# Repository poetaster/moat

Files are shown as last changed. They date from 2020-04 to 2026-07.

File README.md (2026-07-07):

# moat / Keep

A fritzing project to build a semi modular pocket synth. An analog companion to Bastl instruments Kastle. 
Find Kastle source here: https://github.com/bastl-instruments/kastle 

Keep (and moat), unlike Kastle, is analog. It uses a Hex Schmitt-trigger (40106be) for pulses (lfo/osc), a binary ripple counter (4040) for sequencing and an XR 2206 for FM and AM audio. And (very) primitive filters. It sequences using the binary ripple counter, mashed :) Now this actually refers to keep, and Moat has been reborn. See below.

The XR features 2 FM inputs and one AM input. The waveshape of the XR can be tuned from brash triangle to simple sine. The XOR is providing on LFO pulse and one square wave OSC. And everything modulates:)

The moat and keep projects have actuall diverged (see below for Moat and Moat shark) but I haven't had a chance to move to new repo structures.

Some audio samples can be found here: https://poetaster.org/keep . You can also order a kit to make it from me :) I also sell on https://tonetoys.etsy.com and Tindie.

## Sales, yes, I'll sell you some :)

. I'm also on bigcartel at https://tonetoys.bigcartel.com/ ....

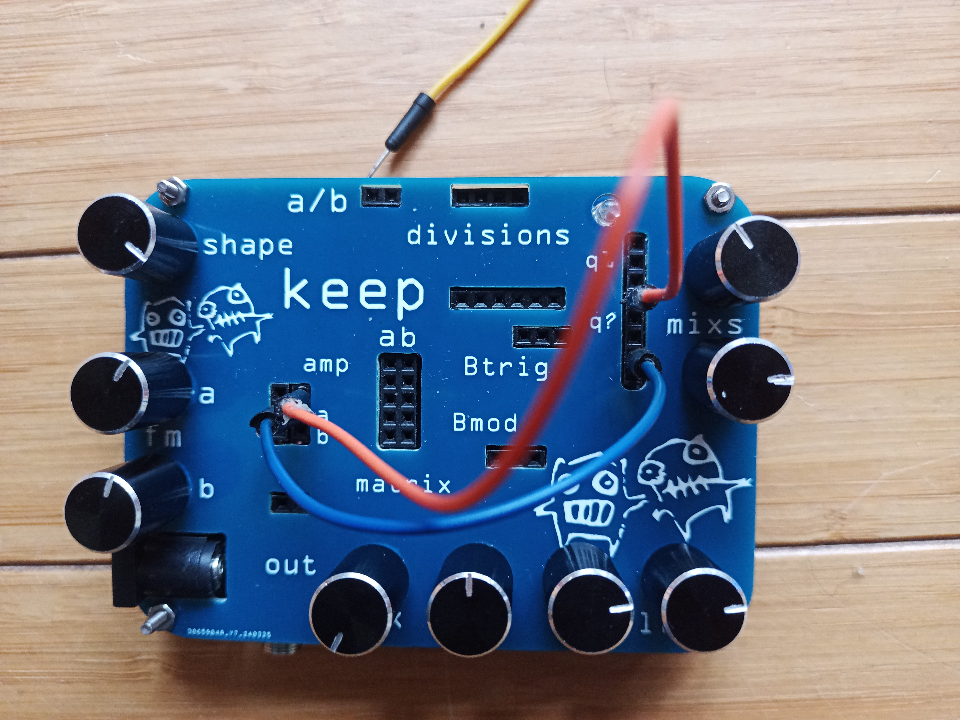
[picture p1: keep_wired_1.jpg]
v4 keep


It's a self-sequencing, semi-modular, pocket synth. Props to minimo, bastl, minty synth etc!

## keep, Version 4 is now in production. 

''Don't use the old moat fritzing projects''.

Version 4 adds waveshaping on the amplitude modulation input, changes the order of the sequencer mix and adds outputs on the rest of the 4040 Q outputs. Otherwise, it adds more space, especially to ease installing vactrol

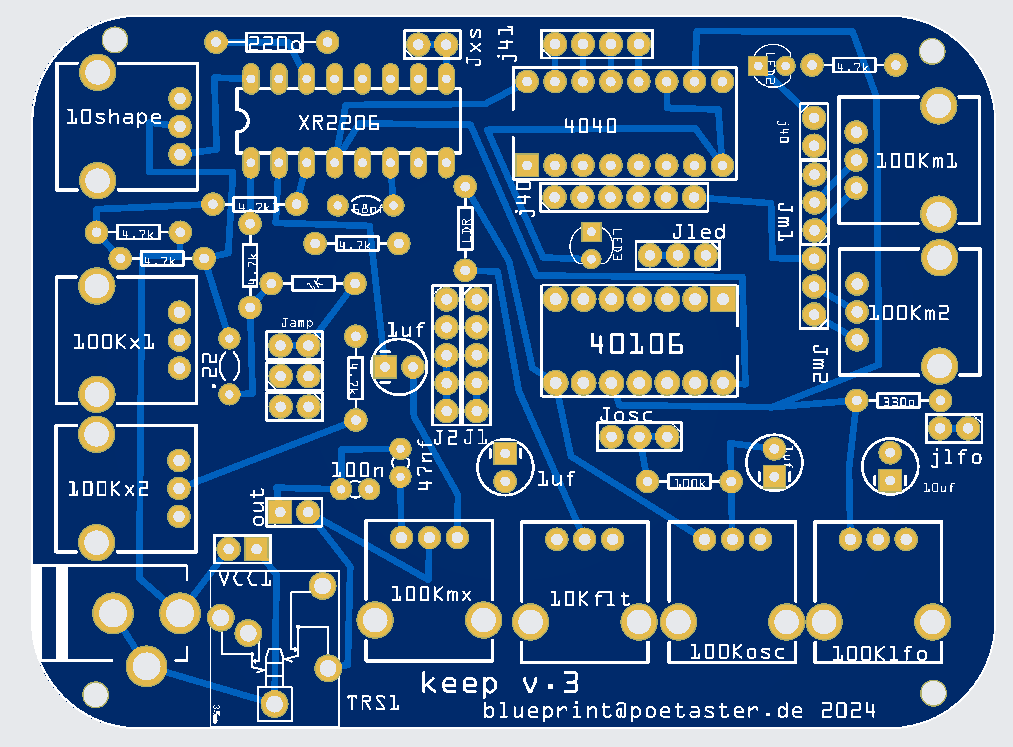
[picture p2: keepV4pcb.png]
PCB view

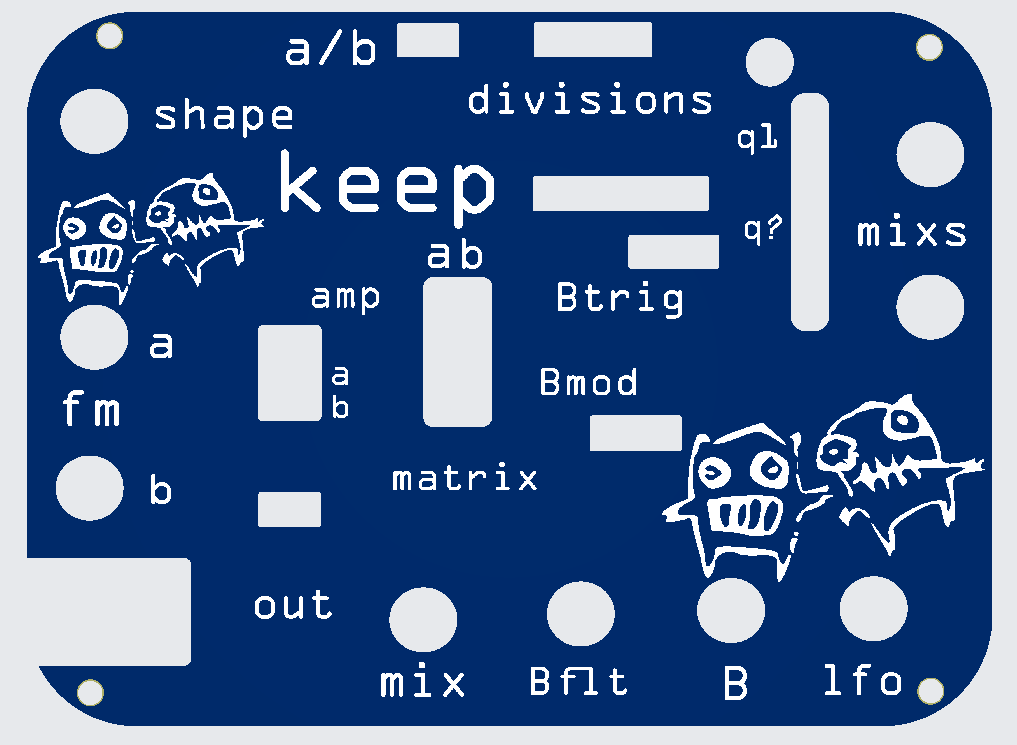
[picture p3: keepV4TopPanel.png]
PCB toppanel


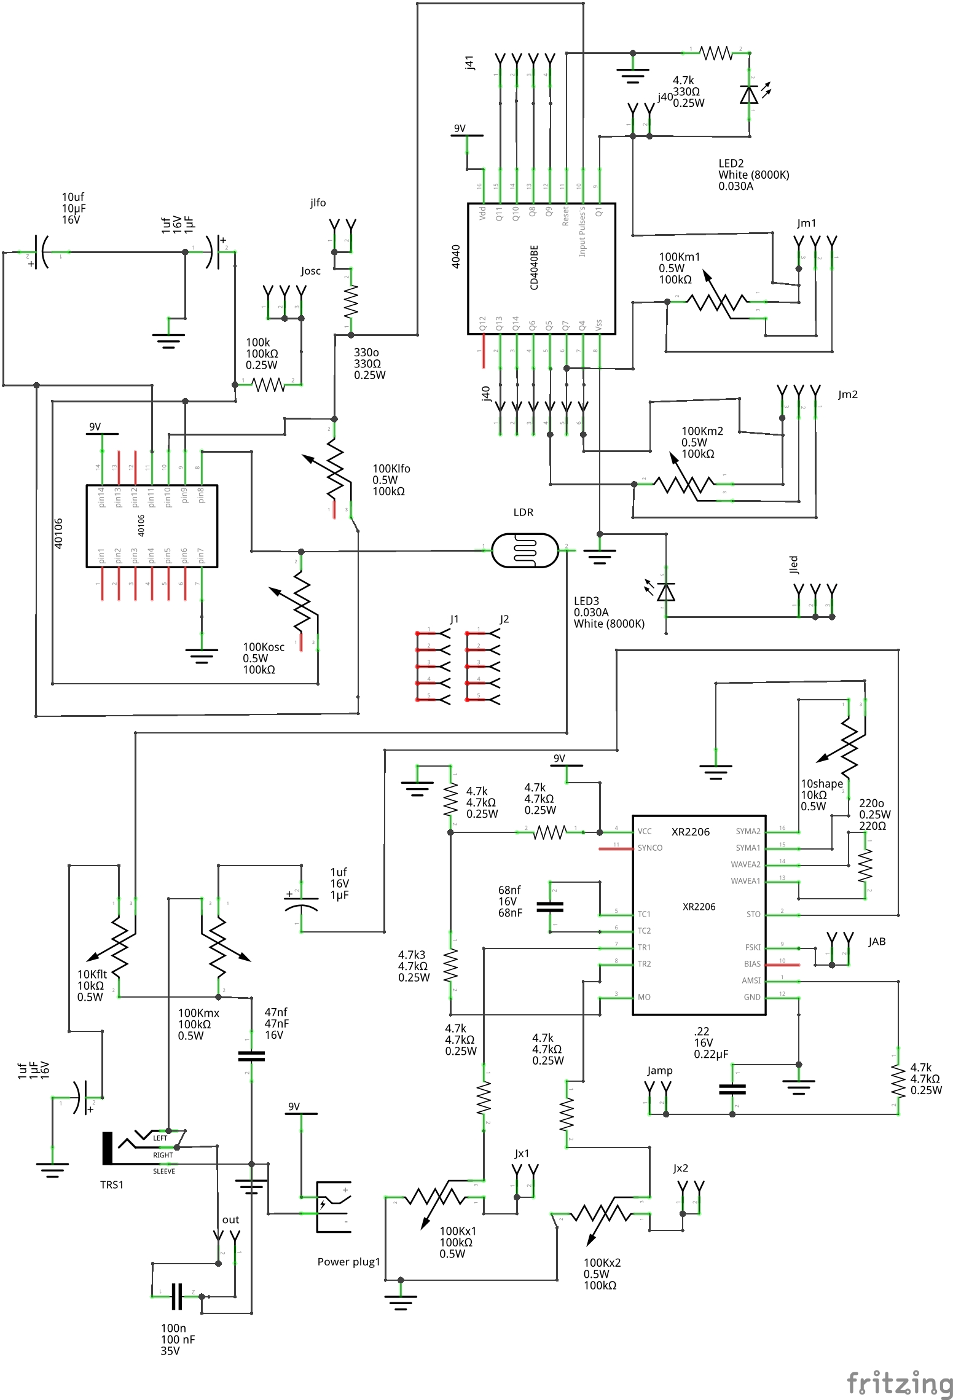
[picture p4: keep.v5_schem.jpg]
schematic


## Moat

I had retired the name as I was thinking of a variant and different behaviour and the old moat became keep. Now, we finally have a moat! A production test run is on order:

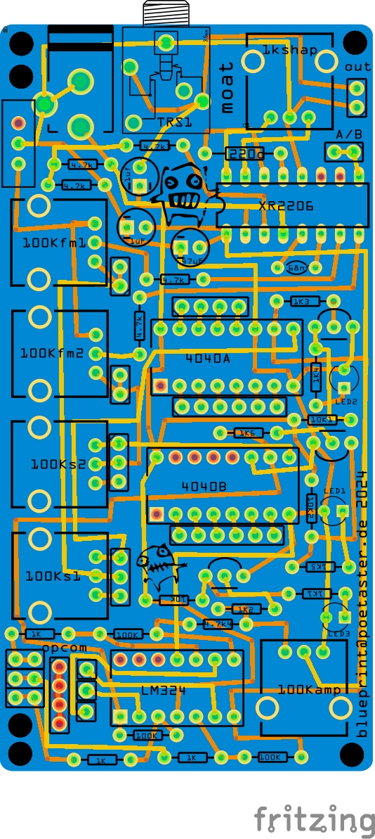
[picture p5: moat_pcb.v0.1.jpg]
Moat pcb


And, the next variant, with a digital delay component, the moat shark (full name, moat shark, lazer arcade):

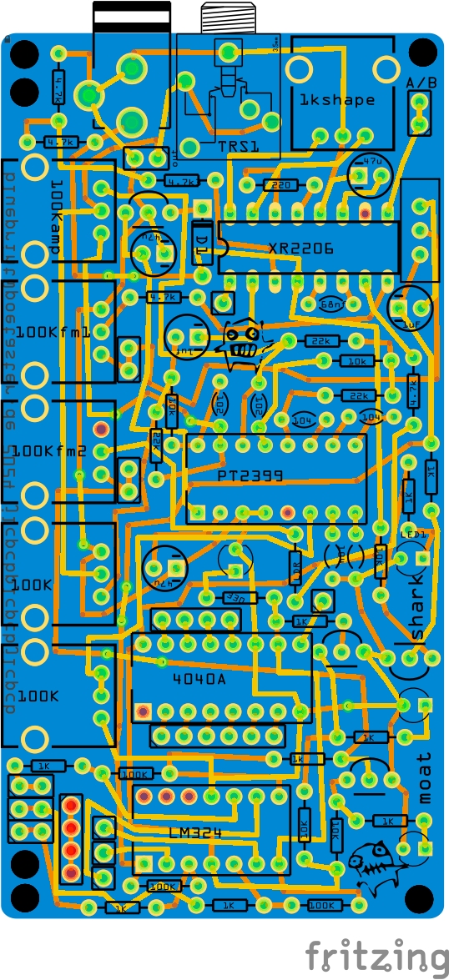
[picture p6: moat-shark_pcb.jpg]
Moat Shark pcb


## Historical builds

Sadly, no pics of the ones in mint tins. Yes, I did that :)

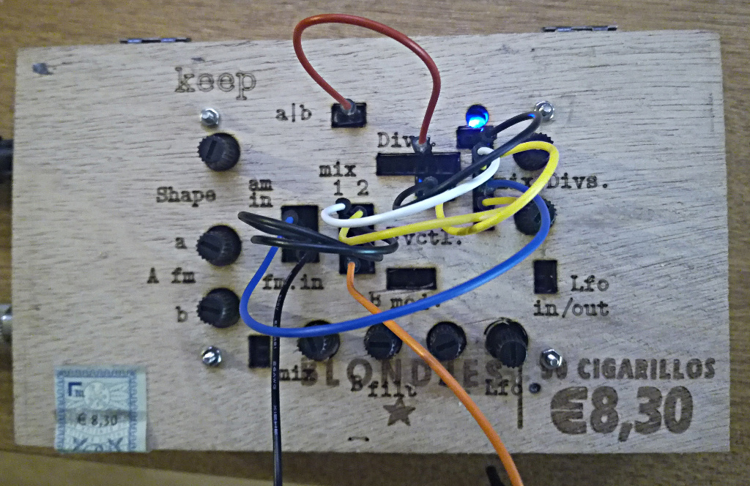
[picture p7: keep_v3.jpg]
Cigarbox prototype laser cut with etched lettering

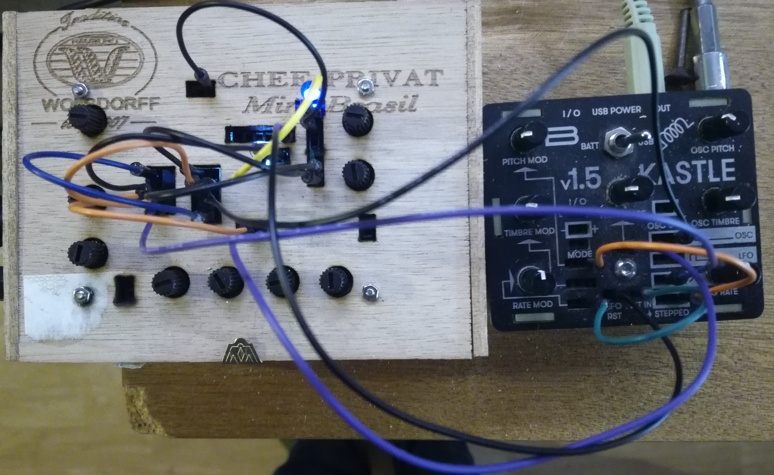
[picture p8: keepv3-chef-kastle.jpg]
Cigarbox prototype with kastle


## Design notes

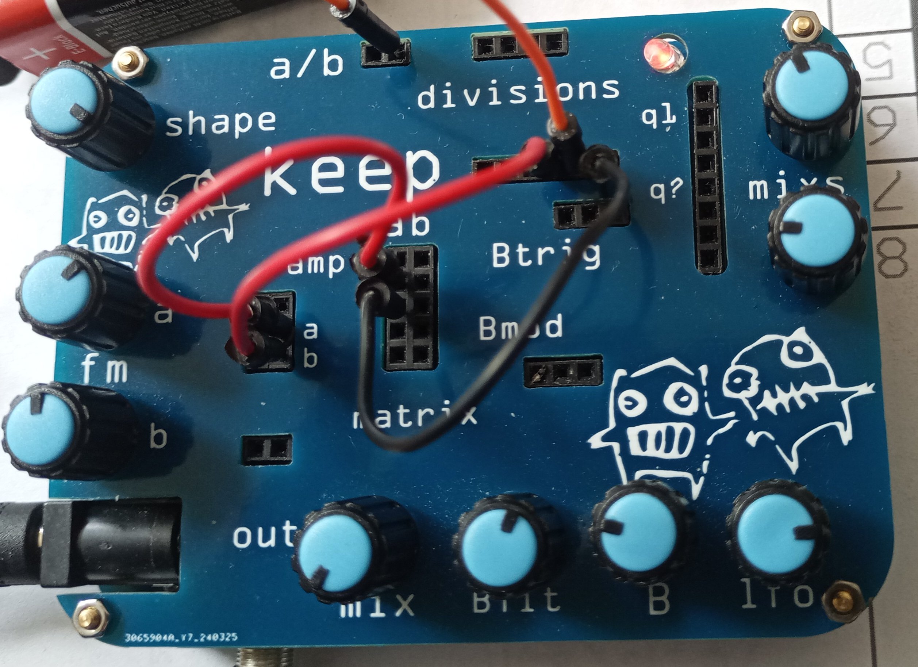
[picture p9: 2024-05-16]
doc/04-keep-intro.jpg

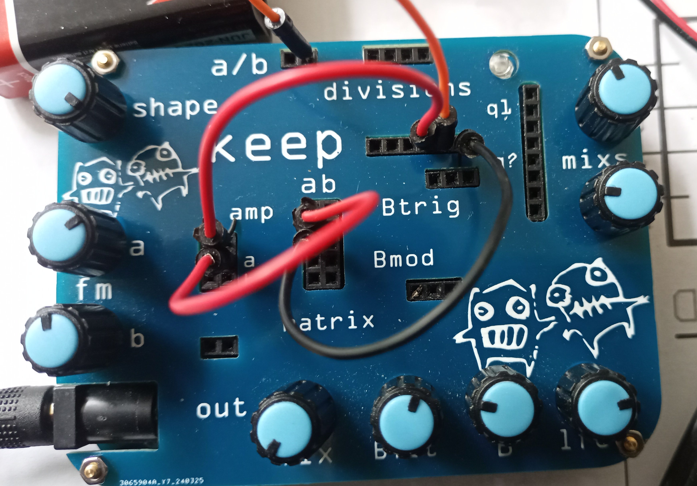
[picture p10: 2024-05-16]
doc/05-keep-intro.jpg

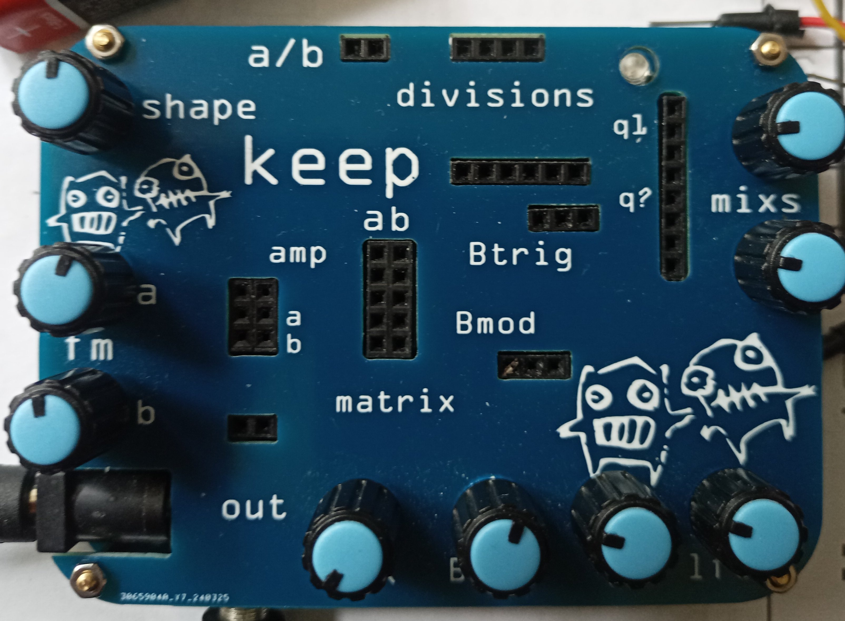
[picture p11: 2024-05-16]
doc/01-keep-intro.jpg

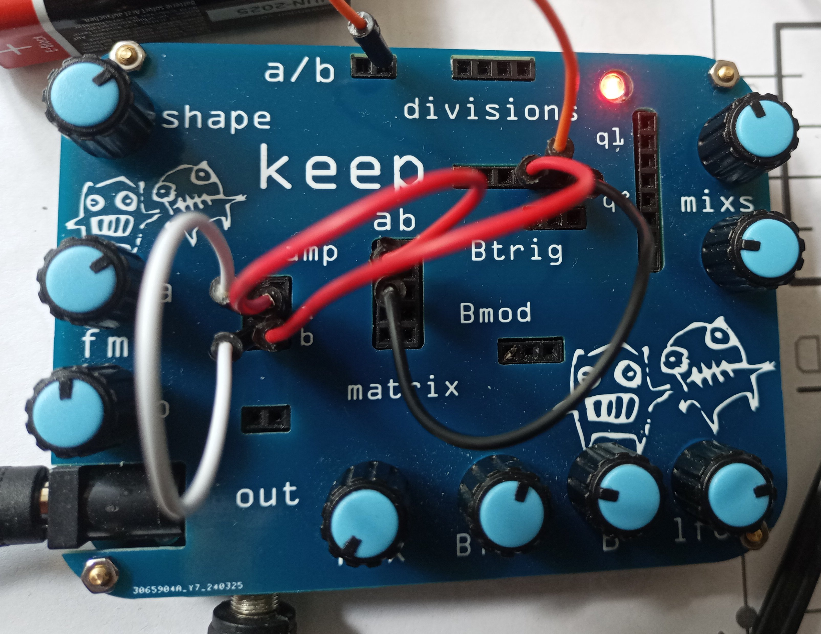
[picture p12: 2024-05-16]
doc/06-keep-intro.jpg

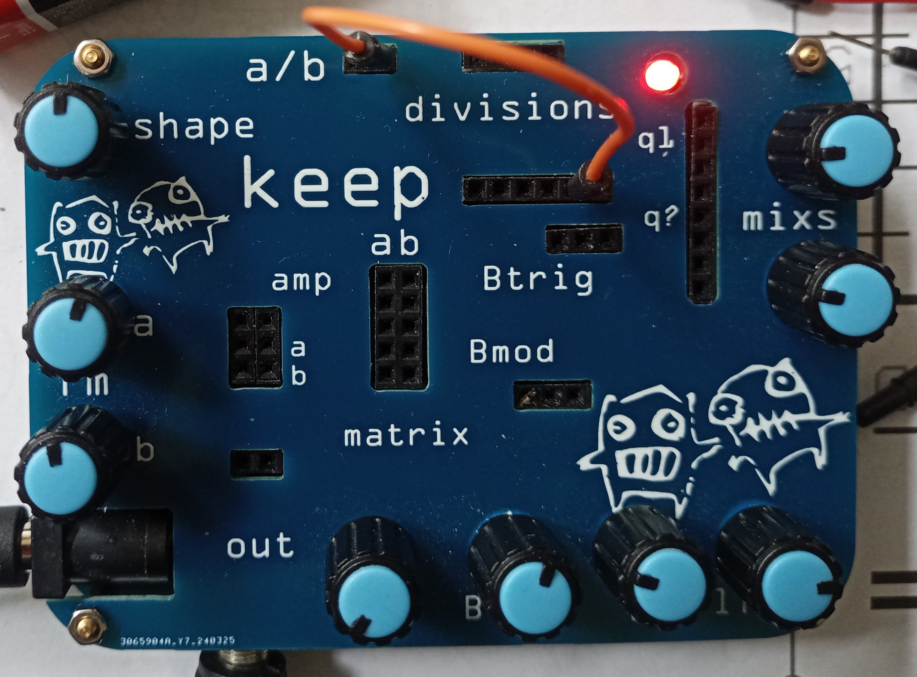
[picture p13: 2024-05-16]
doc/02-keep-intro.jpg

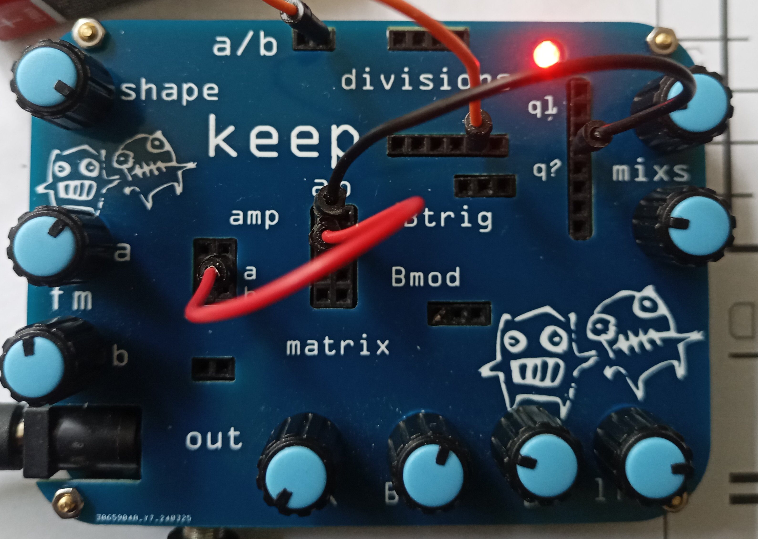
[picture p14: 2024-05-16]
doc/03-keep-intro.jpg

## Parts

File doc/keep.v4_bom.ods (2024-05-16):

Label | Part Type | mn | mpn | part number | cost | price
.22 | Ceramic Capacitor |  |  |  | 0.03 | 0.045
100k | 100kΩ Resistor |  |  |  | 0.01 | 0.015
100Klfo | Rotary Potentiometer (Small) |  |  |  | 0.17 | 0.255
100Km1 | Rotary Potentiometer (Small) |  |  |  | 0.17 | 0.255
100Km2 | Rotary Potentiometer (Small) |  |  |  | 0.17 | 0.255
100Kmx | Rotary Potentiometer (Small) |  |  |  | 0.17 | 0.255
100Kosc | Rotary Potentiometer (Small) |  |  |  | 0.17 | 0.255
100Kx1 | Rotary Potentiometer (Small) |  |  |  | 0.17 | 0.255
100Kx2 | Rotary Potentiometer (Small) |  |  |  | 0.17 | 0.255
100n | Ceramic Capacitor |  |  |  | 0.03 | 0.045
10Kflt | Rotary Potentiometer (Small) |  |  |  | 0.17 | 0.255
10shape | Rotary Potentiometer (Small) |  |  |  | 0.17 | 0.255
10uf | Electrolytic Capacitor |  |  |  | 0.01 | 0.015
1K | 1kΩ Resistor |  |  |  | 0.01 | 0.015
1uf | Electrolytic Capacitor |  |  |  | 0.01 | 0.015
1uf | Electrolytic Capacitor |  |  |  | 0.01 | 0.015
1uf | Electrolytic Capacitor |  |  |  | 0.01 | 0.015
220o | 220Ω Resistor |  |  |  | 0.01 | 0.015
330o | 330Ω Resistor |  |  |  | 0.01 | 0.015
4.7k | 4.7kΩ Resistor |  |  |  | 0.01 | 0.015
4.7k | 4.7kΩ Resistor |  |  |  | 0.01 | 0.015
4.7k | 4.7kΩ Resistor |  |  |  | 0.01 | 0.015
4.7k | 4.7kΩ Resistor |  |  |  | 0.01 | 0.015
4.7k | 330Ω Resistor |  |  |  | 0.01 | 0.015
4.7k | 4.7kΩ Resistor |  |  |  | 0.01 | 0.015
4.7k3 | 4.7kΩ Resistor |  |  |  | 0.01 | 0.015
40106 | 40106 |  |  |  | 0.14 | 0.42
4040 | CD4040E |  |  |  | 0.26 | 0.78
47nf | Ceramic Capacitor |  |  |  | 0.03 | 0.045
68nf | Ceramic Capacitor |  |  |  | 0.03 | 0.045
J1 | Generic female header - 5 pins |  |  |  | 0.06 | 0.09
J2 | Generic female header - 5 pins |  |  |  | 0.06 | 0.09
j40 | Generic female header - 6 pins |  |  |  | 0.06 | 0.09
j40 | Generic female header - 2 pins |  |  |  | 0.06 | 0.09
j41 | Generic female header - 4 pins |  |  |  | 0.05 | 0.075
Jamp | Generic female header - 2 pins |  |  |  | 0.03 | 0.045
Jled | Generic female header - 3 pins |  |  |  | 0.03 | 0.045
jlfo | Generic female header - 2 pins |  |  |  | 0.03 | 0.045
Jm1 | Generic female header - 3 pins |  |  |  | 0.03 | 0.045
Jm2 | Generic female header - 3 pins |  |  |  | 0.03 | 0.045
Josc | Generic female header - 3 pins |  |  |  | 0.03 | 0.045
Jx1 | Generic female header - 2 pins |  |  |  | 0.03 | 0.045
Jx2 | Generic female header - 2 pins |  |  |  | 0.03 | 0.045
Jxs | Generic female header - 2 pins |  |  |  | 0.03 | 0.045
LDR | Photocell (LDR) |  |  |  | 0.07 | 0.105
LED2 | White (8000K) LED |  |  |  | 0.01 | 0.015
LED3 | White (8000K) LED |  |  |  | 0.01 | 0.015
out | Piezo Speaker |  |  |  | 0.06 | 0.09
Power plug1 | Power plug |  |  |  | 0.04 | 0.06
TRS1 | Audio Jack (TRS) 3.5mm |  |  |  | 0.25 | 0.375
VCC1 | 9v – barrel |  |  |  | 1 | 1.5
XR2206 | XR2206 |  |  |  | 2 | 3
 |  |  |  |  |  | 0
PCB | top |  |  |  | 1.5 | 2.25
PCB | bottom |  |  |  | 1.5 | 2.25
Wires | breadboard jumper wire |  |  |  | 0.38 | 0.57
Mounting | nuts&bolts |  |  |  | 0.24 | 0.36
Nobs | Potentiometer Nnob |  |  | 9 | 0.28 | 3.78
9volt adapter |  |  |  |  | 1 | 1
Total |  |  |  |  | 11.1 | 16.65 | kit | built
 |  |  |  |  |  |  | 42 | 78
Amount | Part Type | mn | mpn | part number
1 | 100kΩ Resistor
1 | 1kΩ Resistor
1 | 220Ω Resistor
2 | 330Ω Resistor
6 | 4.7kΩ Resistor
1 | 40106
1 | Audio Jack (TRS) 3.5mm
1 | Battery
1 | CD4040E
4 | Ceramic Capacitor
4 | Electrolytic Capacitor
6 | Generic female header - 2 pins
4 | Generic female header - 3 pins
1 | Generic female header - 4 pins
2 | Generic female header - 5 pins
1 | Generic female header - 6 pins
1 | Photocell (LDR)
1 | Piezo Speaker
1 | Power plug
9 | Rotary Potentiometer (Small)
2 | White (8000K) LED
1 | XR2206
1 | PCB | top
1 | PCB | bottom
12 | Wires | breadboard jumper wire
4 | Mounting | nuts&bolts
9 | Nobs | Potentiometer Nnob

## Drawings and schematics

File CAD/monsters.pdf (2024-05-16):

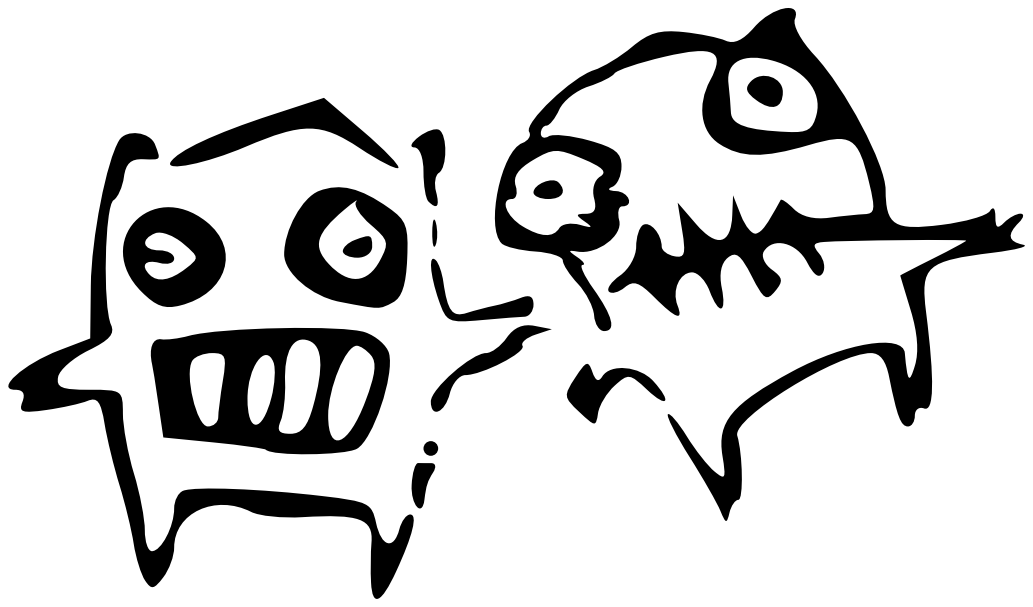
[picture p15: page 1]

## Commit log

2019-02-14 The initial commit.
    [moat.v1.fzz]
2019-11-12 Added v2 fritzing.
    [moat.v2.fzz]
2019-11-12 Slowed it down, since we hardwire the modulators.
    [moat.v2.fzz]
2019-11-13 Removed 2 uneeded parts, since we don't use the xr's sqr out. added 2 mixer js. and layout.
    [moat.v2.fzz]
2019-11-19 Cleaned up pcb view and rearranged the bread board to be a bit easier to build
    [moat.v2.fzz]
2019-11-19 Clean up, pcb.
    [moat.v2.fzz]
2019-11-19 This is going to manufacturing!
    [moat.v2.fzz]
2019-11-20 Last check of typography and values on parts.
    [moat.v2.fzz]
2019-11-21 Going to aisler. now.
    [moat.v2.fzz]
2019-11-27 Damn. It. neglected design rules check. So i've just wasted some time in manufacturing.
    [moat.v2.fzz]
2019-11-27 Can't believe I forgot the design rules check. Well, that's thirty bucks mea culpa!
    [moat.v2.fzz]
2019-11-30 Added old busted as 2.1
    [moat.v2.1.fzz]
2020-01-14 Added a preview image of the pcb.
2020-01-21 Added revision 3 with both a name change reflecting the project name and a layout change moving pots out of the way.
    [keep.v3.fzz]
2020-01-21 Passed design rules.
    [keep.v3.fzz]
2020-01-28 Revision 3 added a DC offset cap, rearranged and tightened layout.
    [keep.v3.fzz]
2020-02-01 Corrected part, from smd to through hole.
    [keep.v3.fzz]
2020-02-01 After a build of version 3, back to the drawing board.
    [keep.v3.fzz, moat.v2.fzz]
2020-02-08 To keep routed lower frequencies and added 4.7k to led out (on first divider) and 4.7k to amp mod in.
    [keep.v3.fzz, moat.v2.fzz]
2020-02-11 Small movement of resistor. Would work in production.
    [keep.v3.fzz]
2020-02-11 Replaced amplitude adjust with a single value. Replacd shape trimmer with pot. Put the timer led back at the first division, with a resistor. Added 4.7k resistor to amplitudue modulation input. This 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
    [keep.v3.fzz]
2020-02-11 Small text correction.
    [keep.v3.fzz]
2020-03-03 Added new picture of pcb. This version removes the trim for amplitude and moves wave shape (tri->sine) up to a proper pot.:wq
2020-03-05 Corrected missing ground connection.
    [keep.v3.fzz]
2020-03-05 Corrected missing ground on the 4040
    [keep.v3.fzz]
2020-03-05 And corrected missing V++
    [keep.v3.fzz]
2020-03-08 Adjusted displayed and chosen value for the XR cap. up to 68nf. broader frequency range.
    [keep.v3.fzz]
2020-03-10 minor spacing, going to pcb now.
    [keep.v3.fzz]
2020-04-17 Added cad files for enclosure top.
2020-04-19 Added two photos and commited last laser cutting settings.
    The laser settings are really dependant on how powerful your laser is:)
2020-04-19 Update README.md
    Added link to audio samples.
2020-05-18 new cad files with labels
2020-06-11 small adjustments,
    [keep.v3.fzz]
2020-06-15 added the gerber files which worked well for https://jlcpcb.com and a new snapshot with the laser etched box
2024-02-15 Fix: begin cleaning up schematic
    [keep.v3.fzz]
2024-03-22 Fix: add a pin to v3 spacing, create v4 first steps
    [keep.v3.fzz, keep.v4.fzz]
2024-03-23 Add: rc network for amplitude modulation input.
    [keep.v4.fzz]
2024-03-24 Release: add div. inputs, spacing.
    [keep.v3.fzz, keep.v4.fzz]
2024-03-24 Add: top board cutouts
    [keep.v4.fzz]
2024-03-24 [Release]: lets see
    [keep.v4.fzz]
2024-05-03 Fixes: for spacing. add gerbers bottom
    [keep.v4.fzz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]
2024-05-03 Cleanup: reorganiz sources, moving old and CAD around
    [keep.v4_bom_csv.csv, keep.v4_top_panel.fzz, moat.v1.fzz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]
2024-05-16 Fix: spacing in the main
    [keep.v4.fzz, keep.v4_bom.ods, keep.v4_top.fzz]
2024-05-16 Oranize: add docs dir and move support files
    [keep.v4_backup.fzz, keep.v4_bom.ods, keep.v4_bom_csv.csv]
2024-05-17 [Release]: version .5
    [keep.v4.fzz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]
2024-05-22 Add: add the gerbers for ease of use
    [keep.v4_contour.gm1, keep.v4_copperBottom.gbl, keep.v4_copperTop.gtl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]
2024-06-04 Readme: tonetoys sales note
    [keep.v4.fzz, keep.v4_top.fzz]
2024-06-04 Fix: cleanup the schematic, fix a ratsline
    [keep.v4.fzz]
2024-06-07 Add: the moat reborn. almost done.
    [moat.fzz]
2024-06-08 [Release]: production version of moat
    [moat.fzz]
2024-06-13 Add: yes, the moat now has a shark. with lasers
    [moat-shark.fzz, moat.fzz]
2024-06-13 Fix: most of the layout is finished.
    [moat-shark.fzz]
2024-06-14 [Release]: moat shark first production run
    [moat-shark.fzz]
2024-06-28 Fixs: minor layout issues.
    [moat-shark.fzz, moat.fzz]
2024-06-28 Fix: change values for mix to get a better balance with the downside of not having absolute silence for the voices. shape reduced since it iss not helpful with more than 1K (or 500 ohms for that matt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
    [keep.v4.fzz]
2024-07-11 Minor: save after open
    [keep.v4.fzz]
2024-07-11 Add: gerber files for thos who need
    [moat-shark_contour.gm1, moat-shark_copperBottom.gbl, moat-shark_copperTop.gtl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]
2024-09-04 Release: latest release files
    [moat-shark.fzz, moat.fzz]
2024-09-13 Fix: pins 10 & 12 ... 10 via 1uF and 12 ground
    [moat.fzz]
2024-09-16 Fix: minor alterations
    [moat-shark.fzz, moat.fzz]
2025-02-09 Add: small mods, switch to ground on b fm and square led.
    [keep.v4.fzz, keep.v4_top.fzz, moat-shark.fzz]
2025-02-25 Fix: move inputs to 3, add 2 pin headers to a/m and Q1. thinner wires
    [moat-shark.fzz]
2025-02-25 Add: gerbers
    [moat-shark_contour.gm1, moat-shark_copperBottom.gbl, moat-shark_copperTop.gtl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]
2025-02-28 Add: these are confirmed gerbers
    [keep.v4_contour.gm1, keep.v4_copperBottom.gbl, keep.v4_copperTop.gtl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]
